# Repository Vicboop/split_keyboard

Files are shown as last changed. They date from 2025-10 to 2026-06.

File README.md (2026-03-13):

# PCBLander

An Split keyboard. This is inspired in moonlander. It has 36 keys and its based on Nice!Nano V2 whit HotSwap for cherry KeySwitch. I got the inspiration and motivation after looking at so many cool designs so wanted to make one of my own.

## Features

72 keys

Wireless

ZMK Firmware

Hotswappable
## PCB








## BOM

| Product | Quantity | Source | Price (€) | Shipping (€) | Link |
|---|---|---|---|---|---|
| Nice! Nano V2.0 | 2 | Aliexpress | 6,04 | | https://pt.aliexpress.com/item/1005009516681283.html |
| Batery 3.7V 600mAh | 2 | Aliexpress | 12,02 | | https://pt.aliexpress.com/item/1005010194727026.html |
| White MX Hotswap | 110 | Aliexpress | 16,66 | | https://pt.aliexpress.com/item/1005005090520759.html |
| Akko Crystal V3 Switch | 80 | Aliexpress | 31,66 | | https://pt.aliexpress.com/item/1005008942995452.html |
| PCB | 1 | JLCPCB | 28,40 | 19,79 | |
| Diode 1N4148W | 100 | Aliexpress | 1,69 | | https://pt.aliexpress.com/item/1005007903085825.html |
| **Total** | | | **112,05**| | |

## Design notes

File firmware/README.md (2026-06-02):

# Firmware ZMK

Este repositório contém agora a configuração-fonte ZMK do PCBLander.

Os `.uf2` antigos nesta pasta são firmwares já compilados do `Keyboardv3`. A configuração nova está nestes ficheiros:

- `build.yaml`
- `config/pcblander.conf`
- `config/pcblander.keymap`
- `boards/shields/pcblander/`
- `.github/workflows/build.yml`
- `zephyr/module.yml`

## Layout

O keymap atual tem 4 camadas, inspirado no layout Moonlander que enviaste:

- `Base`: letras e símbolos principais.
- `Nav`: navegação, setas, `Home`, `End`, `Page Up`, `Page Down`, `F1` a `F12` e Bluetooth.
- `Num`: símbolos e numpad no lado direito.
- `Play`: camada simples para jogo, com letras diretas e menos teclas especiais.

Os botões de polegar principais usam:

- `Desktop`: `Gui+D`.
- `Alfred`: `Alt+Space`.
- `TO 1`: muda para `Nav`.
- `TO 2`: muda para `Num`.
- `TO 3`: muda para `Play`.

## Compilar pelo GitHub Actions

Este é o método mais simples.

1. Faz commit e push destes ficheiros para o GitHub.
2. Abre o repositório no GitHub.
3. Vai a `Actions`.
4. Abre o workflow `Build ZMK firmware`.
5. Quando acabar, descarrega o artifact chamado `firmware`.
6. Extrai o `.zip`.

Devem aparecer:

- `pcblander_left.uf2`
- `pcblander_right.uf2`

O ficheiro `pcblander_left.uf2` já é compilado com suporte para ZMK Studio por USB. O lado direito não precisa de Studio, porque num split wireless o lado esquerdo é o central.

O projeto está fixado em ZMK `v0.3` para evitar que mudanças recentes no ramo `main` quebrem a compilação.

## Compilar localmente com Docker

Instala o Docker Desktop e depois abre PowerShell na raiz do projeto.

```powershell
docker run --rm -it -v "${PWD}:/workspace" -w /workspace zmkfirmware/zmk-build-arm:stable bash
```

Dentro do container:

```bash
west init -l config
west update --fetch-opt=--filter=tree:0
west zephyr-export

west build -s zmk/app -d build/left -b nice_nano_v2 \
  -S studio-rpc-usb-uart -- \
  -DZMK_CONFIG=/workspace/config \
  -DZMK_EXTRA_MODULES=/workspace \
  -DCONFIG_ZMK_STUDIO=y \
  -DSHIELD=pcblander_left

west build -s zmk/app -d build/right -b nice_nano_v2 -- \
  -DZMK_CONFIG=/workspace/config \
  -DZMK_EXTRA_MODULES=/workspace \
  -DSHIELD=pcblander_right
```

Depois de compilar, os ficheiros ficam em:

- `build/left/zephyr/zmk.uf2`
- `build/right/zephyr/zmk.uf2`

## Flash

1. Liga a metade esquerda ao USB.
2. Entra em bootloader no nice!nano.
3. Copia `pcblander_left.uf2` para a drive que aparecer.
4. Repete na metade direita com `pcblander_right.uf2`.
5. Liga as duas metades e faz reset nas duas quase ao mesmo tempo para emparelhar o split.

Assunções atuais:

- `pcblander_left` é a metade central.
- `pcblander_right` é a metade periférica.
- Ambas usam nice!nano/nRF52840.
- A matriz usa diodos `col2row`.

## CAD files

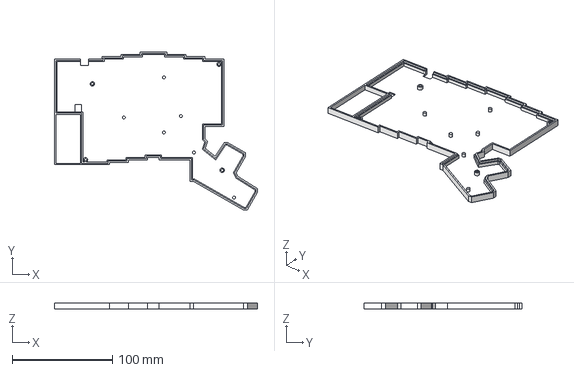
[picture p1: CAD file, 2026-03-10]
Case/Right_Case.step
202.6 x 157.8 x 5.61 mm

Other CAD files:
Case/Left_Side.step

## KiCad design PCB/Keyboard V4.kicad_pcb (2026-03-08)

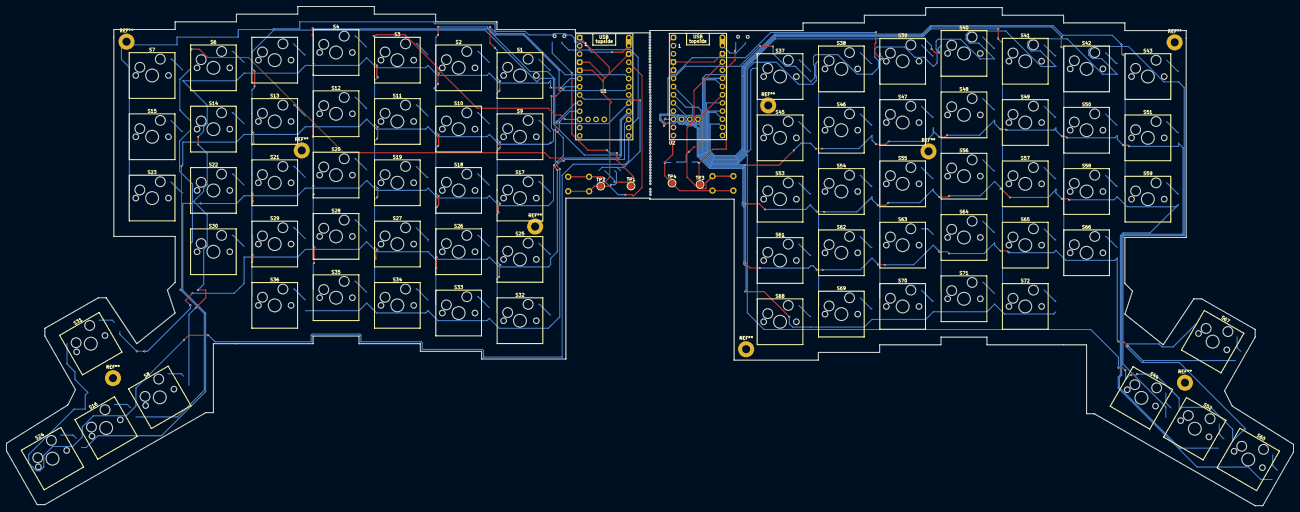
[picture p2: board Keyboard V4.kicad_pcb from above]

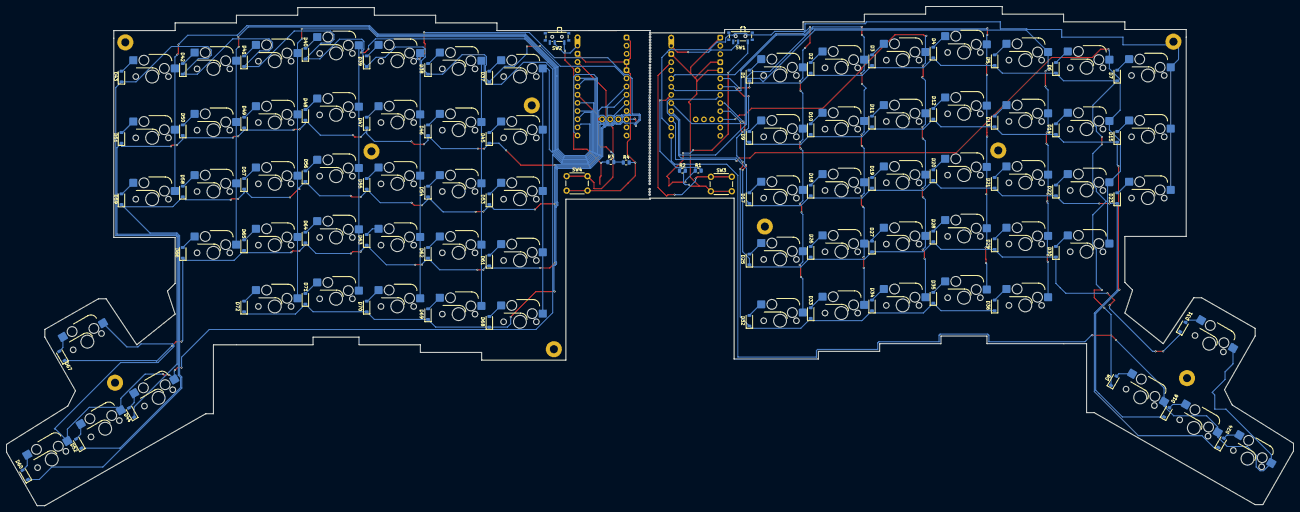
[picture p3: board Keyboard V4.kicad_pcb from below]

Board: 2 copper layers, 399.9 x 155.1 mm, 158 parts (80 on the bottom side), 107 nets.

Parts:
D1, D2, D3, D4, D5, D6, D7, D8, D9, D10, D11, D12, D13, D14, D15, D16, D17, D18, D19, D20, D21, D22, D23, D24, D25, D26, D27, D28, D29, D30, D31, D32, D33, D34, D35, D36, D37, D38, D39, D40, D41, D42, D43, D44, D45, D46, D47, D48, D49, D50, D51, D52, D53, D54, D55, D56, D57, D58, D59, D60, D61, D62, D63, D64, D65, D66, D67, D68, D69, D70, D71, D72: Diode; D_SOD-123
R1, R3: 806k; R_0805_2012Metric
R2, R4: 2M; R_0805_2012Metric
S1, S2, S3, S4, S5, S6, S7, S8, S9, S10, S11, S12, S13, S14, S15, S16, S17, S18, S19, S20, S21, S22, S23, S24, S25, S26, S27, S28, S29, S30, S31, S32, S33, S34, S35, S36, S37, S38, S39, S40, S41, S42, S43, S44, S45, S46, S47, S48, S49, S50, S51, S52, S53, S54, S55, S56, S57, S58, S59, S60, S61, S62, S63, S64, S65, S66, S67, S68, S69, S70, S71, S72: Keyswitch; Hotswap_MX_1.00u
SW1, SW2: SW_SPDT; SW_SPDT_PCM12
SW3, SW4: SW_Push; SW_PUSH_6mm
TP1, TP3: BAT; TestPoint_Pad_D2.0mm
TP2, TP4: GND; TestPoint_Pad_D2.0mm
U1, U2: nice_nano; nice_nano_AH_USBup

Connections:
/Left/BT_PIN: R3.2, R4.1, U2.19 (P0.02-LF)
/Left/COL0: S37.1, S45.1, S53.1, S61.1, S68.1, U2.17 (P0.31-LF)
/Left/COL1: S38.1, S46.1, S54.1, S62.1, S69.1, U2.18 (P0.29-LF)
/Left/COL2: S39.1, S47.1, S55.1, S63.1, S70.1, U2.10 (P0.11)
/Left/COL3: S40.1, S48.1, S56.1, S64.1, S71.1, U2.20 (P1.15-LF)
/Left/COL4: S41.1, S49.1, S57.1, S65.1, S72.1, U2.21 (P1.13-LF)
/Left/COL5: S42.1, S50.1, S58.1, S66.1, U2.22 (P1.11-LF)
/Left/COL6: S43.1, S51.1, S59.1, U2.23 (P0.10-LF)
/Left/COL7: S44.1, S52.1, S60.1, S67.1, U2.24 (P0.09-LF)
/Left/ROW0: D37.1 (K), D38.1 (K), D39.1 (K), D40.1 (K), D41.1 (K), D42.1 (K), D43.1 (K), D44.1 (K), U2.5 (P0.17)
/Left/ROW1: D45.1 (K), D46.1 (K), D47.1 (K), D48.1 (K), D49.1 (K), D50.1 (K), D51.1 (K), D52.1 (K), U2.6 (P0.20)
/Left/ROW2: D53.1 (K), D54.1 (K), D55.1 (K), D56.1 (K), D57.1 (K), D58.1 (K), D59.1 (K), D60.1 (K), U2.7 (P0.22)
/Left/ROW3: D61.1 (K), D62.1 (K), D63.1 (K), D64.1 (K), D65.1 (K), D66.1 (K), D67.1 (K), U2.8 (P0.24)
/Left/ROW4: D68.1 (K), D69.1 (K), D70.1 (K), D71.1 (K), D72.1 (K), U2.9 (P1.00)
/Left/VBAT: R3.1, SW2.1 (A), TP3.1
/Right/BT_PIN: R1.2, R2.1, U1.19 (P0.02-LF)
/Right/COL0: S1.1, S9.1, S17.1, S25.1, S32.1, U1.17 (P0.31-LF)
/Right/COL1: S2.1, S10.1, S18.1, S26.1, S33.1, U1.18 (P0.29-LF)
/Right/COL2: S3.1, S11.1, S19.1, S27.1, S34.1, U1.10 (P0.11)
/Right/COL3: S4.1, S12.1, S20.1, S28.1, S35.1, U1.20 (P1.15-LF)
/Right/COL4: S5.1, S13.1, S21.1, S29.1, S36.1, U1.21 (P1.13-LF)
/Right/COL5: S6.1, S14.1, S22.1, S30.1, U1.22 (P1.11-LF)
/Right/COL6: S7.1, S15.1, S23.1, U1.23 (P0.10-LF)
/Right/COL7: S8.1, S16.1, S24.1, S31.1, U1.24 (P0.09-LF)
/Right/ROW0: D1.1 (K), D2.1 (K), D3.1 (K), D4.1 (K), D5.1 (K), D6.1 (K), D7.1 (K), D8.1 (K), U1.5 (P0.17)
/Right/ROW1: D9.1 (K), D10.1 (K), D11.1 (K), D12.1 (K), D13.1 (K), D14.1 (K), D15.1 (K), D16.1 (K), U1.6 (P0.20)
/Right/ROW2: D17.1 (K), D18.1 (K), D19.1 (K), D20.1 (K), D21.1 (K), D22.1 (K), D23.1 (K), D24.1 (K), U1.7 (P0.22)
/Right/ROW3: D25.1 (K), D26.1 (K), D27.1 (K), D28.1 (K), D29.1 (K), D30.1 (K), D31.1 (K), U1.8 (P0.24)
/Right/ROW4: D32.1 (K), D33.1 (K), D34.1 (K), D35.1 (K), D36.1 (K), U1.9 (P1.00)
/Right/VBAT: R1.1, SW1.1 (A), TP1.1
GND: R2.2, R4.2, SW3.2, SW4.2, TP2.1, TP4.1, U1.3 (GND), U1.4 (GND), U1.14 (GND), U1.28 (GND), U2.3 (GND), U2.4 (GND), U2.14 (GND), U2.28 (GND)
unnamed: D1.2 (A), S1.2
unnamed: D2.2 (A), S2.2
unnamed: D3.2 (A), S3.2
unnamed: D4.2 (A), S4.2
unnamed: D5.2 (A), S5.2
unnamed: D6.2 (A), S6.2
unnamed: D7.2 (A), S7.2
unnamed: D8.2 (A), S8.2
unnamed: D9.2 (A), S9.2
unnamed: D10.2 (A), S10.2
unnamed: D11.2 (A), S11.2
unnamed: D12.2 (A), S12.2
unnamed: D13.2 (A), S13.2
unnamed: D14.2 (A), S14.2
unnamed: D15.2 (A), S15.2
unnamed: D16.2 (A), S16.2
unnamed: D17.2 (A), S17.2
unnamed: D18.2 (A), S18.2
unnamed: D19.2 (A), S19.2
unnamed: D20.2 (A), S20.2
unnamed: D21.2 (A), S21.2
unnamed: D22.2 (A), S22.2
unnamed: D23.2 (A), S23.2
unnamed: D24.2 (A), S24.2
unnamed: D25.2 (A), S25.2
unnamed: D26.2 (A), S26.2
unnamed: D27.2 (A), S27.2
unnamed: D28.2 (A), S28.2
unnamed: D29.2 (A), S29.2
unnamed: D30.2 (A), S30.2
unnamed: D31.2 (A), S31.2
unnamed: D32.2 (A), S32.2
unnamed: D33.2 (A), S33.2
unnamed: D34.2 (A), S34.2
unnamed: D35.2 (A), S35.2
unnamed: D36.2 (A), S36.2
unnamed: D37.2 (A), S37.2
unnamed: D38.2 (A), S38.2
unnamed: D39.2 (A), S39.2
unnamed: D40.2 (A), S40.2
unnamed: D41.2 (A), S41.2
unnamed: D42.2 (A), S42.2
unnamed: D43.2 (A), S43.2
unnamed: D44.2 (A), S44.2
unnamed: D45.2 (A), S45.2
unnamed: D46.2 (A), S46.2
unnamed: D47.2 (A), S47.2
unnamed: D48.2 (A), S48.2
unnamed: D49.2 (A), S49.2
unnamed: D50.2 (A), S50.2
unnamed: D51.2 (A), S51.2
unnamed: D52.2 (A), S52.2
unnamed: D53.2 (A), S53.2
unnamed: D54.2 (A), S54.2
unnamed: D55.2 (A), S55.2
unnamed: D56.2 (A), S56.2
unnamed: D57.2 (A), S57.2
unnamed: D58.2 (A), S58.2
unnamed: D59.2 (A), S59.2
unnamed: D60.2 (A), S60.2
unnamed: D61.2 (A), S61.2
unnamed: D62.2 (A), S62.2
unnamed: D63.2 (A), S63.2
unnamed: D64.2 (A), S64.2
unnamed: D65.2 (A), S65.2
unnamed: D66.2 (A), S66.2
unnamed: D67.2 (A), S67.2
unnamed: D68.2 (A), S68.2
unnamed: D69.2 (A), S69.2
unnamed: D70.2 (A), S70.2
unnamed: D71.2 (A), S71.2
unnamed: D72.2 (A), S72.2
unnamed: SW1.2 (B), U1.13 (BAT+), U1.29 (BAT+)
unnamed: SW2.2 (B), U2.13 (BAT+), U2.29 (BAT+)
unnamed: SW3.1, U1.15 (RST)
unnamed: SW4.1, U2.15 (RST)

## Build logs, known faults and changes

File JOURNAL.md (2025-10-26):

<!--
  ===================    !!READ THIS NOTICE!!   ====================
  DO NOT edit this file manually. Your changes WILL BE OVERWRITTEN!
  This journal is auto generated and updated by Hack Club Blueprint.
  To edit this file, please edit your journal entries on Blueprint.
  ==================================================================
-->

## 10/24/2025 9 AM - I started working on the project  

Hi,
In past 2 days i was been flowing the tutorial of blueprint to build my split keyboard i alredy finished the schematics and im assigning the foot print now



## 10/24/2025 2 PM - Make everything again  

WhatsApp Image 2025-10-24 at 14.17.43_a7db7e8b.jpg
Ok, i was looking for videos and i saw tons of videos and keyboards designs i redo everything from scrach and new layout is something like this

Now im thinking how to display the keys

## 10/24/2025 3 PM - Layout defined  


Finaly i finished the layout. im having troubles whit the 3d viewer but i will see what i can do, everything is going well besides of that, i sill strat to try to resolve the problem  

## 10/25/2025 12 PM - Redo for more keys  

Whit help in the hackclub slack i found a new controler for my board because i want more keys (https://pt.aliexpress.com/item/1005009516681283.html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) 
my new diagram

and the layout that i will do


## 10/25/2025 4 PM - Routed left side  


Finished the right side pcb including the routing, i will do the left side tomorrow wnd shearch for a batery online, until now i already have done the pcb and shematic 3 times

## 10/26/2025 - Routed PCB  


I fineshed the pcb design and i will use the battery(https://pt.aliexpress.com/item/1005009372894259.html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"order"%3A"-1"%2C"eval"%3A"1"%2C"fromPage"%3A"search"%7D&pdp_npi=6%40dis%21EUR%215.95%215.30%21%21%216.75%216.01%21%402103956a17614822298805096e86af%2112000048901745270%21sea%21PT%210%21ABX%211%210%21n_tag%3A-29910%3Bd%3Aebac7c7d%3Bm03_new_user%3A-29895&curPageLogUid=5oiDX8gfIbZv&utparam-url=scene%3Asearch%7Cquery_from%3A%7Cx_object_id%3A1005009372894259%7C_p_origin_prod%3A)

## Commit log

2026-03-06 Enhance README with project details and image
    Added project description and PCB image to README.
2026-03-06 Add image of the keyboard PCB to README
    Added an image to the README for visual reference.
2026-03-06 Update README with PCB images
    Added images for left and right PCB views.
2026-03-06 Add BOM section to README
    Added BOM section with total cost information.
2026-03-07 Update and rename Keyboard V4.kicad_pcb to PCB/Keyboard V4.kicad_pcb
    [Keyboard V4.kicad_pcb]
2026-03-07 Rename Keyboard V4.kicad_prl to PCB/Keyboard V4.kicad_prl
2026-03-07 Rename Keyboard V4.kicad_pro to PCB/Keyboard V4.kicad_pro
2026-03-07 Update and rename Keyboard V4.kicad_sch to PCB/Keyboard V4.kicad_sch
    [Keyboard V4.kicad_sch]
2026-03-10 Update and rename Left_Side.step to Case/Left_Side.step
    [Left_Side.step]
2026-03-10 Update and rename Right_Case.step to Case/Right_Case.step
    [Right_Case.step]
2026-03-13 Revise BOM with product information and totals
    Updated BOM table with product details and prices.
2026-06-02 Pin ZMK to v0.3
